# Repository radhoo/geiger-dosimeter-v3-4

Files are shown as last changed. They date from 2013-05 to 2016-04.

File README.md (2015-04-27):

# geiger-dosimeter-v3-4

Given all my previous experience with Geiger Counters (see the uRADMonitor project, http://www.uradmonitor.com 
), I have decided to conceive a portable, easy to build, radiation dosimeter. 
I didn't have much need for yet another dosimeter (with my Radex 1706 or Terra-P), but I know there are several 
people not affording a commercial unit, but wanting to have their own radiation measurement tool. So here is this project, 
giving you just that: an efficient, stable, easy to build construction for all your radiation dosimetry needs.

Short description
I've started from scratch, designing a complete dosimeter unit around the Atmel Atmega8 microcontroller and a Russian 
Geiger Muller tube. Here you'll see the STS-1 tube, for high gamma doses, but the dosimeter can be used with any other 
tubes such as SBM-20, LND-712 or more sensitive ones such as the SBM-19 or the pancake tube SI-14B. Changing the tube 
requires changing the software, to adjust the dose conversion calculation. This circuit can be used with almost any geiger 
tube, as even the inverter's output voltage driving the tube is adjustable in the software.

I've been invited to show this dosimeter on a TV Show, on TVR Timisoara (video is in Romanian):
http://www.youtube.com/watch?v=WXmPR-FNbIg

Functionality
Similar to my uRADMonitor, the microcontroller takes care of everything:
1. Generates a variable duty PWM signal using Timer1, to drive the 400V inverter needed to operate the Geiger tube; 
The invertor doesn't need a multiplier, as the ferrite's transformer secondary puts out exactly the amount required. 
The transformer is made on a A22 ferrite core, with 16 turns in the primary and 600 in the secondary.
2. Uses one ADC port to measure the inverter's voltage and adjust the PWM duty cycle for constant output 
(exactly 400V for stable operation)
3. Counts the time, using Timer0 so we can compute the dose
4. Uses interrupt INT0 to count the pulses produced by the Geiger tube
5. Drives a 2x16 LCD to output the results.
Some other circuits on the Internet come with improper 400V inverters (some people seem not to be able to design a 
proper inverter), they are redundant (using 555's and additional components, when the microcontroller can take care 
of EVERYTHING), use the wrong signal detection/counter circuit, or other small defects that result in wrong measurements. 
Not to mention the controversial aspect of computing dose in sieverts out of counts per minute.
Given all the wrong designs out there, my detector tries to fill in some of the gaps. So here is exactly what you need: 
a stable design, with several improvements made over time, all packed in this nice construction that you can easily replicate.

More on http://www.pocketmagic.net/?p=3342 

Circuit diagram
http://www.pocketmagic.net/wp-content/uploads/2012/12/geiger_counter_schematics.png

License
This work is free software, licensed under GPL v2; you can redistribute it and/or modify it under the terms of the GNU General 
Public License as published by the Free Software Foundation; either version 2 of the License, or (at your option) any later 
version. For other licensing options, feel free to contact me. 

Additional resources

More details available on my blog: http://www.pocketmagic.net/?p=3342

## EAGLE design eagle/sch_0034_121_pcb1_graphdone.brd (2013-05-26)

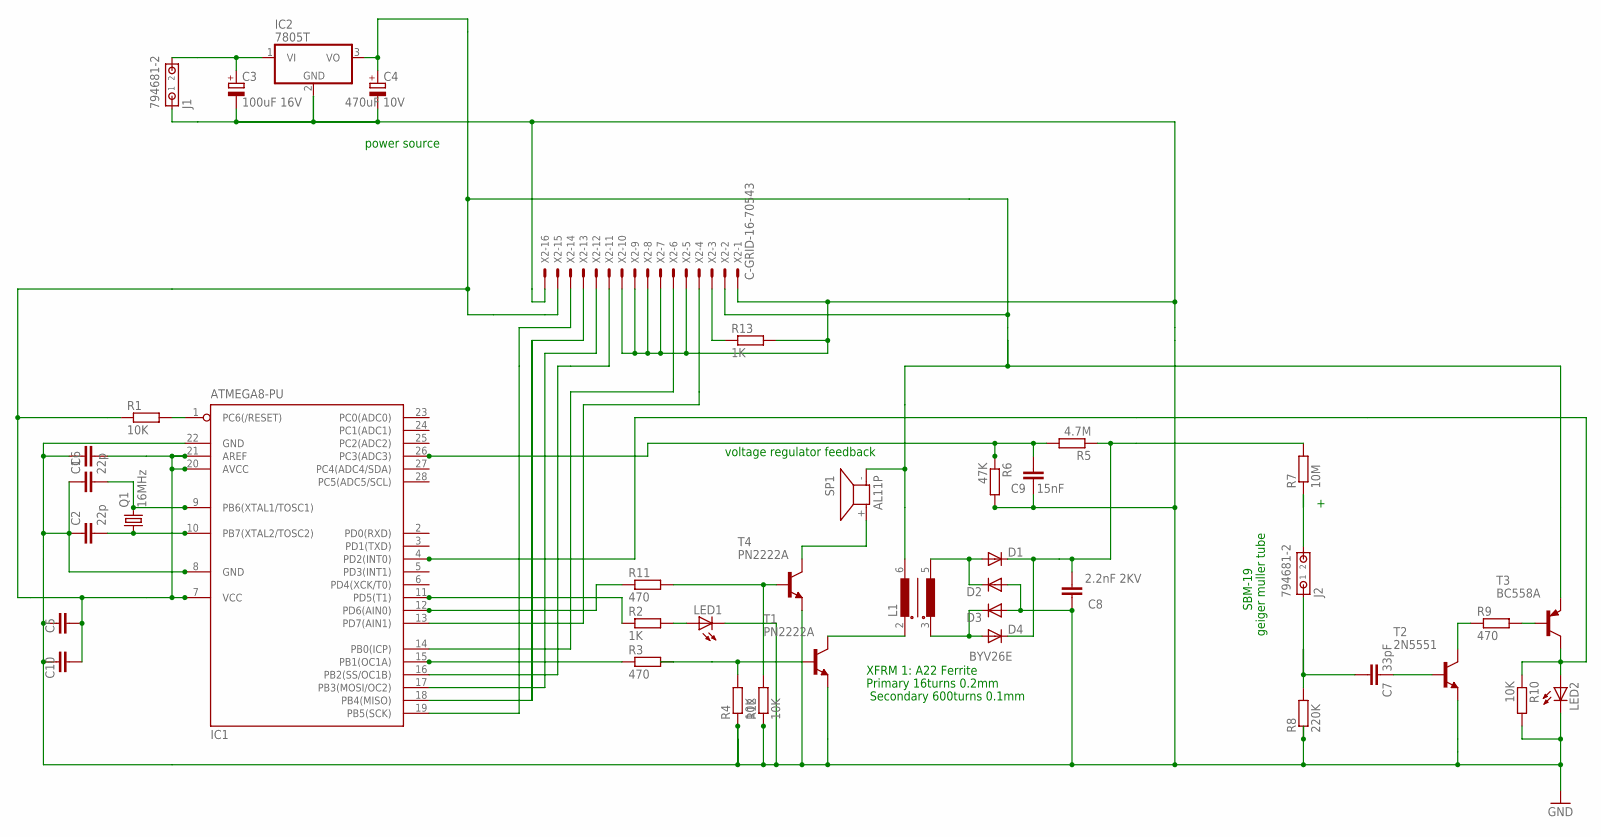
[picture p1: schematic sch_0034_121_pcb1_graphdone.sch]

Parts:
C1, C2: 22p; C025-024X044
C3: 100uF 16V; E2,5-6E
C4: 470uF 10V; E2,5-6E
C5, C6, C10: 100nF; C025-024X044
C7: 33pF; C025-024X044
C8: 2.2nF 2KV; C025-024X044
C9: 15nF; C025-024X044
D1, D2, D3: DIODE-D-7.5; D-7.5
D4: BYV26E; D-7.5
IC1: ATMEGA8-PU; DIL28-3
IC2: 7805T; TO220H
J1, J2: 794681-2
L1: RM6-2; RM5-4
LED1, LED2: LED3MM
Q1: 16MHz; HC49U-V
R1, R4, R10, R12: 10K; 0204/7
R2, R13: 1K; 0204/7
R3, R9, R11: 470; 0204/7
R5: 4.7M; 0204/7
R6: 47K; 0204/7
R7: 10M; 0204/7
R8: 220K; 0204/7
SP1: AL11P
T1, T4: PN2222A; TO92-EBC
T2: 2N5551; TO92-EBC
T3: BC558A; TO92-EBC
X2: C-GRID-16-70543; 70543-16

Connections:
GND: C1.1, C2.1, C3.-, C4.-, C5.2, C6.2, C8.1, C9.1, C10.2, D2.A, D3.A, IC1.8 (GND), IC1.22 (GND), IC2.2 (GND), J1.1, LED1.K (C), LED2.K (C), R4.1, R6.2, R8.1, R10.2, R12.1, R13.2, T1.E, T2.E, T4.E, X2.1, X2.5, X2.7, X2.8, X2.9, X2.10, X2.16
unnamed: C1.2, IC1.9 (PB6(XTAL1/TOSC1)), Q1.2
unnamed: C2.2, IC1.10 (PB7(XTAL2/TOSC2)), Q1.1
unnamed: IC1.18 (PB4(MISO)), X2.13
unnamed: IC1.11 (PD5(T1)), R2.1
unnamed: R3.2, R4.2, T1.B
unnamed: SP1.+ (2), T4.C
unnamed: C4.+, C5.1, C6.1, C10.1, IC1.7 (VCC), IC1.20 (AVCC), IC1.21 (AREF), IC2.3 (VO), L1.6 (W1E), R1.1, SP1.- (1), T3.E, X2.2, X2.15
unnamed: IC1.12 (PD6(AIN0)), R11.1
unnamed: R11.2, R12.2, T4.B
unnamed: LED1.A, R2.2
unnamed: C3.+, IC2.1 (VI), J1.2
unnamed: L1.2 (W1A), T1.C
unnamed: C7.2, J2.1, R8.2
unnamed: D3.C, D4.A, L1.3 (W2A)
unnamed: D1.A, D2.C, L1.5 (W2E)
unnamed: C7.1, T2.B
unnamed: C8.2, D1.C, D4.C, R5.1, R7.2
unnamed: C9.2, IC1.26 (PC3(ADC3)), R5.2, R6.1
unnamed: J2.2, R7.1
unnamed: R9.1, T2.C
unnamed: R9.2, T3.B
unnamed: IC1.4 (PD2(INT0)), LED2.A, R10.1, T3.C
unnamed: IC1.13 (PD7(AIN1)), X2.4
unnamed: IC1.1 (PC6(/RESET)), R1.2
unnamed: IC1.15 (PB1(OC1A)), R3.1
unnamed: IC1.19 (PB5(SCK)), X2.14
unnamed: IC1.17 (PB3(MOSI/OC2)), X2.12
unnamed: R13.1, X2.3
unnamed: IC1.14 (PB0(ICP)), X2.6
unnamed: IC1.16 (PB2(SS/OC1B)), X2.11

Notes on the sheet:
XFRM 1: A22 Ferrite
Primary 16turns 0.2mm
Secondary 600turns 0.1mm
voltage regulator feedback
geiger muller tube
power source
SBM-19

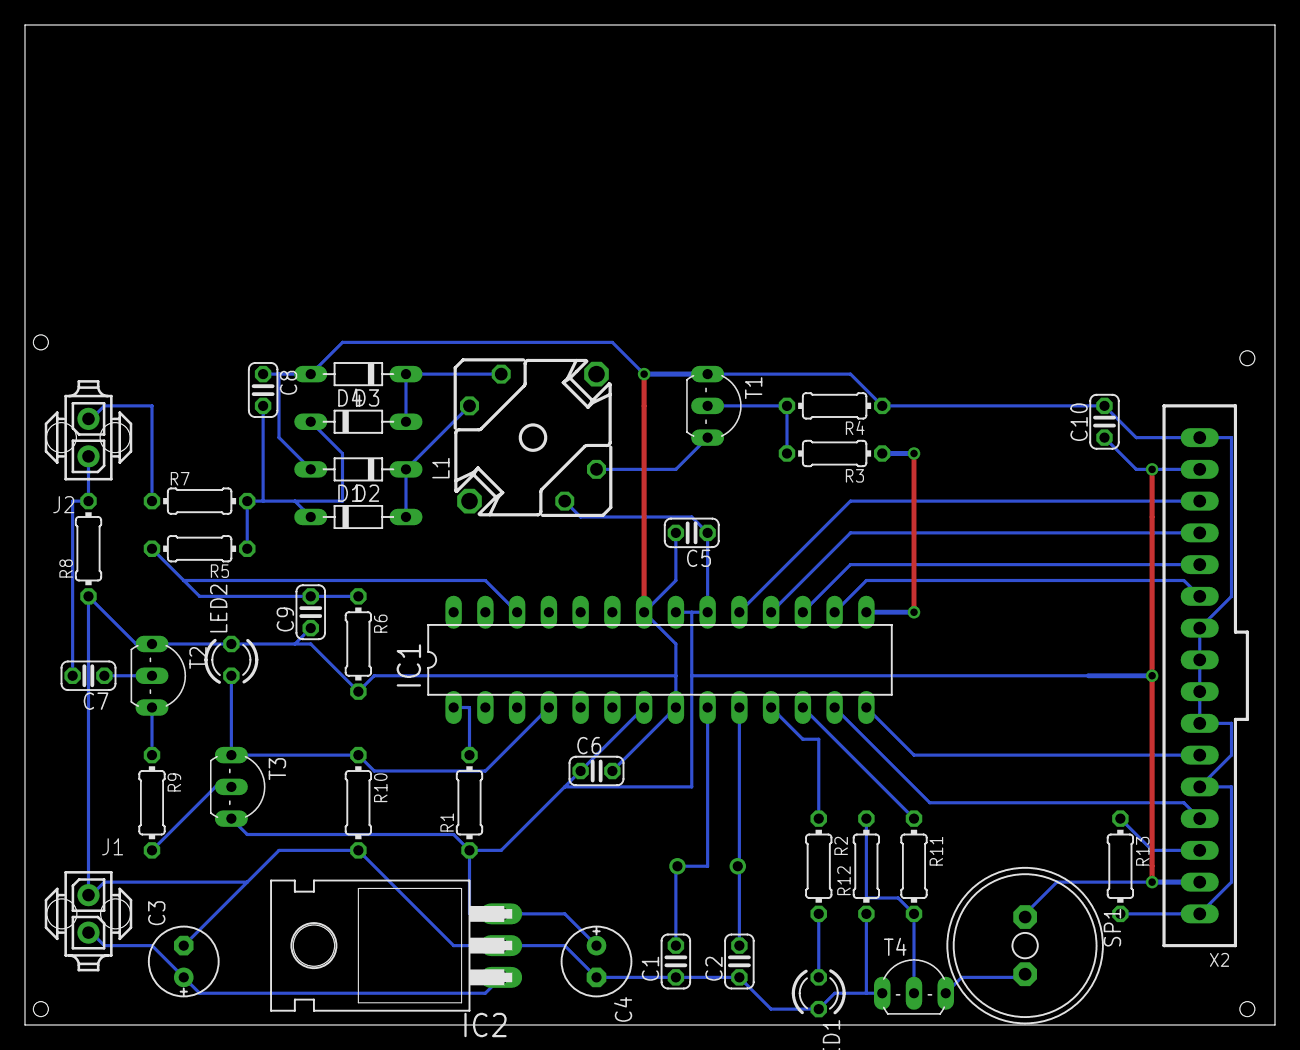
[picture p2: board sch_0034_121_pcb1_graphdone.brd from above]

Board: 2 copper layers, 100.0 x 80.0 mm, 41 parts (1 on the bottom side), 31 nets.

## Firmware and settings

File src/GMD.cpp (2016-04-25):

/*
 * Geiger Dosimeter 3.4
 * http://www.pocketmagic.net 
 *
 * Copyright (c) 2013 by Radu Motisan , radu.motisan@gmail.com
 *
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
 * For more information on the GPL, please go to:
 * http://www.gnu.org/copyleft/gpl.html
 *
 */

/*
 * CS can be configured in hw_enc28j60.h
 * Configure mymac and myip below
 */

#include <avr/io.h>
#include <avr/interrupt.h>
#include "timeout.h" // defines F_CPU

// lcd
#include "lcd/hd44780.h"

#include "spk.h"
#include "led.h"
volatile int
/* 
 * GEIGER 
 */
		g_nTimeSec = 0, g_nTimeMin = 0, g_nTimeHour = 0, 
		g_nTimeMilis = 0, gs_geiger_pulses = 0, /*gs_geiger_total = 0,*/
/* 
 * INVERTER
 */
		g_nPWMDuty = 100,//254 ,
		g_nTubeVoltage = 0,  
		g_nTubeVoltageThreshold = 400, tolv = 5,
		g_nCPM = 0, g_nLastCPM = 0, ready = 0;						
/* 
 * CPM TO uSv/h linear conversion : acceptable only for low doses of high energy gamma radiation
 * Background dose: 0.12uSv/h
 *
 * TUBE:
 * STS-1    18pulses/min=18cpm -> 0.12uSv/h;  factor = 0.12/18= 0.006
 * SBM-19   80pulses/min=80cpm -> 0.12uSv/h;  factor = 0.12/80= 0.0015
 */
float	usvhfactor = 0.006,	//preconfigured for given tube
		usvhold = 0;

bool 	bRefresh = true, bBeep = false;

// Reads the ADC port specified by i
uint16_t adcread(uint8_t i)
{
	ADMUX = i;
	ADCSRA = (1<<ADEN) | (1<<ADIF) | (1<<ADSC)|7;
	loop_until_bit_is_set(ADCSRA, ADIF);
	uint16_t v = ADCL;
	v|= (ADCH<<8);
	return v;
}

int readHV() {
	float	Vref		= 5.0; //Vref set to 5V
	float supplyadc = adcread(3);
	uint16_t R1 = 4600;//KO
	uint16_t R2 = 47;//KO
	return (int)( supplyadc / 1024.0 * (R1+R2) / R2 * Vref );
}

/*
	timer0 overflow interrupt
	event to be executed every  1.024ms here
*/
ISR (TIMER0_OVF_vect)  
{
	g_nTimeMilis ++;
	if (g_nTimeMilis >= 976) {
		bRefresh = true;
		 if (g_nTimeSec<59) {
			g_nTimeSec++; 
		 }			
		 else { 
			g_nTimeSec = 0; 
			// one full minute!
			g_nCPM = gs_geiger_pulses;
			ready = 1;
			//gs_geiger_total+=gs_geiger_pulses;
			// 
			gs_geiger_pulses = 0;
			
			if (g_nTimeMin<59) 
				g_nTimeMin++; 
			else {
				g_nTimeMin = 0;
				// one full hour!
				//gs_geiger_total = 0; // reset every hour
				if (g_nTimeHour<24)
					g_nTimeHour++;
				else 
					g_nTimeHour = 0;
			}				
		 }	
		 
		 g_nTimeMilis = 0; // 976 x 1.024ms ~= 1000 ms = 1sec
	}
}			

/*
	This interrupt handler is triggered each time a rising edge is
	detected on INT0, which on a ATmega8 is PD2
*/

ISR(INT0_vect) {
	gs_geiger_pulses++;
	bBeep = true;
}
 


/*
 * Main entry point
 */
int main(void) {
	
	_delay_ms(500);
	
	// Set ADCSRA Register in ATMega168
	ADCSRA = (1<<ADEN) | (1<<ADPS2) | (1<<ADPS1);

	// Set ADMUX Register in ATMega168
	ADMUX=0;
	
	_delay_ms(200);


	SPKInit();
	LEDInit();
	/*
	 *  1.CONFIGURE INTERRUPT INT0  to count pulses from Geiger Counter, connected on PIN PD2
	 */
	// Configure INT0 to trigger on rising edge
	MCUCR |= _BV(ISC00) | _BV(ISC01);
	// Configure INT0 to fire interrupts
	GICR |= _BV(INT0);
	
	/*
	 * 2.CREATE Timer T0 to count seconds, will trigger callback ISR (TIMER0_OVF_vect)  
	 */
	TIMSK |= (1 << TOIE0);
	// set prescaler to 64 and start the timer
	TCCR0 |= (1 << CS01) | (1 << CS00);
	// start timer and interrupts
	sei();
	// =====

	/*
	 * 3.CREATE PWM with Timer T1 to drive inverter for regulated voltage, needed for the Geiger tube
	 */
	TCCR1A = 0;     // disable all PWM on Timer1 whilst we set it up
	// set the frequency FCPU/(ICR1 * PRESCALLING) Hz 
	// 16MHz, prescalling 8x: 
	// ICR1 = 50; //40KHz
	// ICR1 = 100; //20KHz
	// ICR1 = 200; //10KHz
	// ICR1 = 1000;//2KHz
	
	// 16MHz, prescalling 1x:
	// ICR1 = 100;//160KHz
	// ICR1 = 400;//40KHz
	// ICR1 = 800;//20KHz
	ICR1 = 800;  // 20KHz 74
	
	// 8Mhz, prescalling 1x: (half as for 16Mhz)
	//ICR1 = 400; //20 KHz
	
	// Configure timer 1 for Fast PWM mode via ICR1, with no prescaling (1X)
	TCCR1B = (1 << WGM13) | (1<<WGM12) | (1 << CS10); //CS11 = 8x prescalling , CS10 = 1x prescalling
	// Set PB1 and PB2 as outputs
	DDRB |= _BV(1);
	TCCR1A |= (1 << COM1A1) | (1<< CS11); // set none-inverting mode and start PWM
	
	OCR1A = (int)((float)ICR1 * (float)g_nPWMDuty/1000.0); //50% g_nPWMDuty 
	
	// prepare LCD init
	_delay_ms(200);

	lcd_init();
	lcd_clrscr();
	lcd_string("Geiger Dosimeter  \npocketmagic.net    ");
	_delay_ms(1500);
	int i = 0;
	
	// program loop
	while(1){
		i++;
		
		// check voltage every two seconds, and adjust duty cycle to regulate voltage
		//if (g_nTimeSec % 2 == 0) {
			g_nTubeVoltage = readHV();
			if (g_nTubeVoltage >= g_nTubeVoltageThreshold + tolv) { // we need to decrease voltage
				if (g_nPWMDuty > 10) g_nPWMDuty --; //1%
				OCR1A = (int)((float)ICR1 * (float)g_nPWMDuty/1000.0); //
			}
			if (g_nTubeVoltage <= g_nTubeVoltageThreshold - tolv) { // we need to increase voltage
				if (g_nPWMDuty < 350) g_nPWMDuty ++;//35%
				OCR1A = (int)((float)ICR1 * (float)g_nPWMDuty/1000.0); //
			}
		//}

		float usvh = 0;
		
		// we compute the dose every 5 seconds
		if ((g_nTimeSec > 0) && g_nTimeSec % 5 == 0) {
			g_nLastCPM = (60.0 * gs_geiger_pulses) / g_nTimeSec;
			usvh = usvhfactor * g_nLastCPM;
			usvhold = usvh;
		}
		
		if (bRefresh) {
			bRefresh = false;

			// move LCD cursor back to home position: we prepare a new display content
			lcd_home();

			// 2x16 Output
			// first line: dose in microsieverts and in counts per minute
			// second line: voltage on tube, second counter, pulse counter, duty cycle
			
			//XXXXXXXXXXXXXXXX
			// 0.12uSvh 18CPM
			//400V 50s 18 245

			lcd_string_format("%2.2fuSvh %dCPM     \n%dV %ds %d %d    ",
				usvhold,g_nLastCPM,
				g_nTubeVoltage, g_nTimeSec,gs_geiger_pulses, g_nPWMDuty );
		}
		
		if (bBeep) {
			bBeep = false;
			SPKSet(1);
			LEDSet(1);
			_delay_us(100);
			SPKSet(0);
			LEDSet(0);
		}

	}
	return (0);
} 

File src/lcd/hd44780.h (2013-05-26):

/*
 * HD44780 LCD Minimal interface for Atmega microcontrollers
 * http://www.pocketmagic.net/
 *
 * Copyright (c) 2013 by Radu Motisan , radu.motisan@gmail.com
 *
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
 * For more information on the GPL, please go to:
 * http://www.gnu.org/copyleft/gpl.html
 */

#pragma once
#include <stdio.h>
#include <avr/io.h> 
//--------------------------------CONFIGURE LCD------------------------------------------------------//
#define LCD_LINES		 2			// number of visible lines of the display
#define LCD_DISP_LENGTH  16     	// visibles characters per line of the display 
#define LCD_START_LINE1  		 0x00   // DDRAM address of first char of line 1 
#define LCD_START_LINE2  		 0x40   // DDRAM address of first char of line 2 
#define LCD_START_LINE3  		 0x14   // DDRAM address of first char of line 3 
#define LCD_START_LINE4  		 0x54   // DDRAM address of first char of line 4 

//Purpose: work with a LCD display
#define LCD_4BIT_D4_PORT   PORTB     	// port for 4bit data bit 0 		//D5 poz:3 connector...[digits 0,1,...]
#define LCD_4BIT_D4_PIN    2          // pin for 4bit data bit 0  		
#define LCD_4BIT_D5_PORT   PORTB     	// port for 4bit data bit 1 		//D6
#define LCD_4BIT_D5_PIN    3          // pin for 4bit data bit 1  
#define LCD_4BIT_D6_PORT   PORTB     	// port for 4bit data bit 2 		//D7
#define LCD_4BIT_D6_PIN    4          // pin for 4bit data bit 2  
#define LCD_4BIT_D7_PORT   PORTB     	// port for 4bit data bit 3 		//B0
#define LCD_4BIT_D7_PIN    5          // pin for 4bit data bit 3  
#define LCD_RS_PORT      PORTD     	// port for RS line         		//D3 poz:1 connector
#define LCD_RS_PIN       7        // pin  for RS line         
#define LCD_E_PORT       PORTB     	// port for Enable line     		//D4 poz:2 connector
#define LCD_E_PIN        0          // pin  for Enable line     
//#define LCD_RW_PORT      LCD_PORT // port for RW line UNUSED - we only WRITE
//#define LCD_RW_PIN       5        // pin  for RW line UNUSED - we only WRITE
//---------------------------------------------------------------------------------------------------//

// instruction register bit positions, see HD44780U data sheet 
#define LCD_CLR               	0x0    	// DB0: clear display                  
#define LCD_HOME              	0x1    	// DB1: return to home position        
#define LCD_ENTRY_MODE        	0x2     // DB2: set entry mode                 
#define LCD_ENTRY_INC         	0x1     // DB1: 1=increment, 0=decrement     
#define LCD_ENTRY_SHIFT       	0x0     // DB2: 1=display shift on           
#define LCD_ON                	0x3     // DB3: turn lcd/cursor on             
#define LCD_ON_DISPLAY        	0x2     // DB2: turn display on              
#define LCD_ON_CURSOR         	0x1     // DB1: turn cursor on               
#define LCD_ON_BLINK          	0x0     // DB0: blinking cursor ?          
#define LCD_MOVE              	0x4     // DB4: move cursor/display            
#define LCD_MOVE_DISP         	0x3     // DB3: move display (0-> cursor) ?  
#define LCD_MOVE_RIGHT        	0x2     // DB2: move right (0-> left) ?      
#define LCD_FUNCTION          	0x5     // DB5: function set                   
#define LCD_FUNCTION_8BIT     	0x4     // DB4: set 8BIT mode (0->4BIT mode) 
#define LCD_FUNCTION_2LINES   	0x3     // DB3: two lines (0->one line)      
#define LCD_FUNCTION_10DOTS   	0x2     // DB2: 5x10 font (0->5x7 font)      
#define LCD_CGRAM             	0x6     // DB6: set CG RAM address             
#define LCD_DDRAM             	0x7     // DB7: set DD RAM address             
#define LCD_BUSY              	0x7     // DB7: LCD is busy                    

// set entry mode: display shift on/off, dec/inc cursor move direction 
#define LCD_ENTRY_DEC            0x04	// display shift off, dec cursor move dir 
#define LCD_ENTRY_DEC_SHIFT      0x05   // display shift on,  dec cursor move dir 
#define LCD_ENTRY_INC_           0x06   // display shift off, inc cursor move dir 
#define LCD_ENTRY_INC_SHIFT      0x07   // display shift on,  inc cursor move dir 

// display on/off, cursor on/off, blinking char at cursor position 
#define LCD_DISP_OFF             0x08   // display off                            
#define LCD_DISP_ON              0x0C   // display on, cursor off                 
#define LCD_DISP_ON_BLINK        0x0D   // display on, cursor off, blink char     
#define LCD_DISP_ON_CURSOR       0x0E   // display on, cursor on                  
#define LCD_DISP_ON_CURSOR_BLINK 0x0F   // display on, cursor on, blink char      

// move cursor/shift display 
#define LCD_MOVE_CURSOR_LEFT     0x10   // move cursor left  (decrement)          
#define LCD_MOVE_CURSOR_RIGHT    0x14   // move cursor right (increment)          
#define LCD_MOVE_DISP_LEFT       0x18   // shift display left                     
#define LCD_MOVE_DISP_RIGHT      0x1C   // shift display right                    

// function set: set interface data length and number of display lines 
#define LCD_FUNCTION_4BIT_1LINE  0x20   // 4-bit interface, single line, 5x7 dots 
#define LCD_FUNCTION_4BIT_2LINES 0x28   // 4-bit interface, dual line,   5x7 dots 
#define LCD_FUNCTION_8BIT_1LINE  0x30   // 8-bit interface, single line, 5x7 dots 
#define LCD_FUNCTION_8BIT_2LINES 0x38   // 8-bit interface, dual line,   5x7 dots 


//
#define LCD_MODE_DEFAULT     ((1<<LCD_ENTRY_MODE) | (1<<LCD_ENTRY_INC) )
// address of data direction register of port x
#define	LCD_DDR(x) 		(*(&x - 1))      



extern int g_nCurrentLine;
		
inline void lcd_e_high() { LCD_E_PORT  |=  _BV(LCD_E_PIN); }
inline void lcd_e_low() { LCD_E_PORT  &= ~_BV(LCD_E_PIN); }
inline void lcd_rs_high() { LCD_RS_PORT |=  _BV(LCD_RS_PIN); }
inline void lcd_rs_low() { LCD_RS_PORT &= ~_BV(LCD_RS_PIN); }
// flush channel E
void lcd_toggle_e(void);
// PURPOSE: send a character or an instruction to the LCD
void lcd_write(uint8_t data,uint8_t rs) ;			
// PURPOSE:  send an instruction to the LCD
void lcd_instr(uint8_t instr);

// PURPOSE:  Initialize LCD to 4 bit I/O mode
void lcd_init();
// PURPOSE:  send a character to the LCD
void lcd_char(uint8_t data);
// PURPOSE:  send a null terminated string to the LCD eg. char x[10]="hello!";
void lcd_string(char *text);	
void lcd_string_format(char *szFormat, ...);
// PURPOSE:  Set cursor to specified position
//           Input:    x  horizontal position  (0: left most position)
//                     y  vertical position    (0: first line)
void lcd_gotoxy(uint8_t x, uint8_t y);
// PURPOSE:  Move cursor on specified line
void lcd_setline(uint8_t line);
// PURPOSE:  Clear display and set cursor to home position
void lcd_clrscr(void);
// FUNCTION: lcd_home
// PURPOSE:  Set cursor to home position
void lcd_home(void);

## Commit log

2013-05-26 version 3.4.121.A
    [sch_0034_121_pcb1_graphdone.brd, sch_0034_121_pcb1_graphdone.sch]
2016-04-25 ported to eclipse, fixed default duty cycle, pulse length and refresh mechanism
    [GMD.cpp, hd44780.h, led.h]
